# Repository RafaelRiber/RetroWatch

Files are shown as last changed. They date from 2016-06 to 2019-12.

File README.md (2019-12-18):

# RetroWatch
 <p align="center">
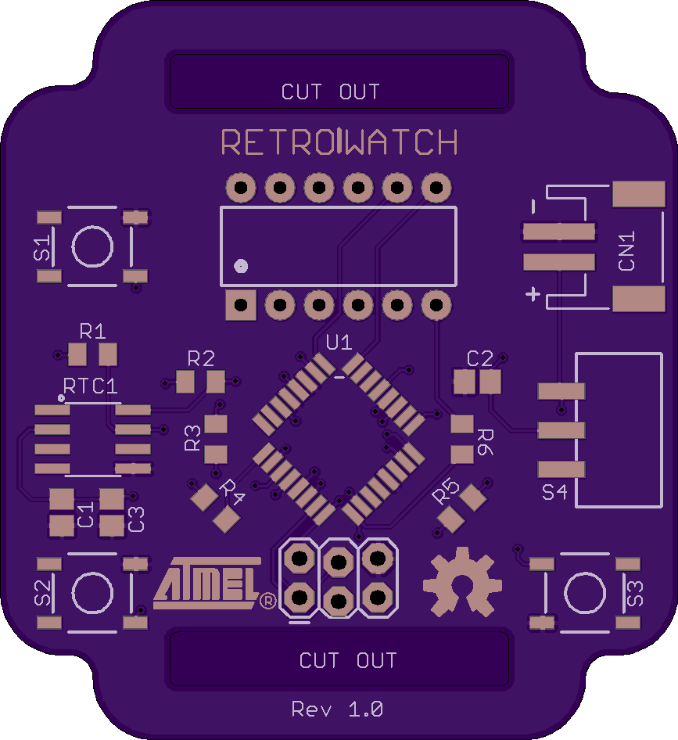
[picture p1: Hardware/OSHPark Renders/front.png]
 
 <em>Front</em>
 <p align="center">
 <b>OSHPark renders</b>
 </p>
 
## Short description
A retro watch, based around the HP QDSP-6064 Bubble display, used in 70s HP calculators like the [HP-35](https://en.wikipedia.org/wiki/HP-35). The display is controlled by an Atmel ATMega328P-AU MCU with Arduino code, and the time is kept by a Maxim DS3231 Real-Time Clock module, that stays connected to the LiPo battery at all times, keeping time even when the microcontroller and display are not powered.
The code is open source, licensed under the MIT License, and the harware is fully open-source.

### Featured on:
[Hackaday.com blog post by Elliot Williams](http://hackaday.com/2016/06/25/easy-bubble-watch-oozes-retro-charm/)

[Hackaday.io project page](https://hackaday.io/project/12402-retrowatch)
  
## Hardware
### PCB
The board design was made in Eagle, has been tested and works. A 500 mAh [LiPo Battery from Adafruit](https://adafru.it/1578) fits perfectly under the board. It can be freely modified. It can also directly be ordered on the OSHPark website: 
<p align="center"></p>

(DISCLAIMER: I am in no way affiliated with Atmel. I just put the Atmel logo on the PCB to show the circuit uses an Atmel chip, which I really like !)

### Bill Of Materials
You can find the BOM [here](https://github.com/RafaelRiber/RetroWatch/blob/master/BOM.md).
  
## Software
The software was written in Arduino code, is licensed under MIT License, and can be uploaded on the microcontroller via ISP.
Be sure to set the desired time in the code prior to uploading, to set the time registers on the RTC.

Functions of the code include:
* Hours, minutes and seconds
* Day, month, year, day of year, day in week, week in year.
* Stopwatch (start, stop, reset)
* Temperature reading from the real-time-clock's built-in thermometer (accurate to about 3°C)
* Brightness setting in software, saved to EEPROM to save even if the watch is powered off.
 
To be able to upload the code on the watch, an Arduno IDE board file for an "ATMega328 on a breadboard" running at 8 MHz with the internal crystal, is needed. You can find it here: https://www.arduino.cc/en/Tutorial/ArduinoToBreadboard under "Minimal Circuit (Eliminating the External Clock)"
### Required Libraries
1. [Chrono library by thomasfredericks](https://github.com/thomasfredericks/Chrono)
2. [Pushbutton library from Pololu](http://pololu.github.io/pushbutton-arduino/)
3. [RTCLib by Adafruit Industries](https://github.com/adafruit/RTClib)
4. [SevSeg by SparkFun](https://github.com/sparkfun/SevSeg)

### Planned Sofware Functions
• ~~Menu structure for mode selection~~ DONE !

• ~~Year~~ DONE !

• Time set on the watch

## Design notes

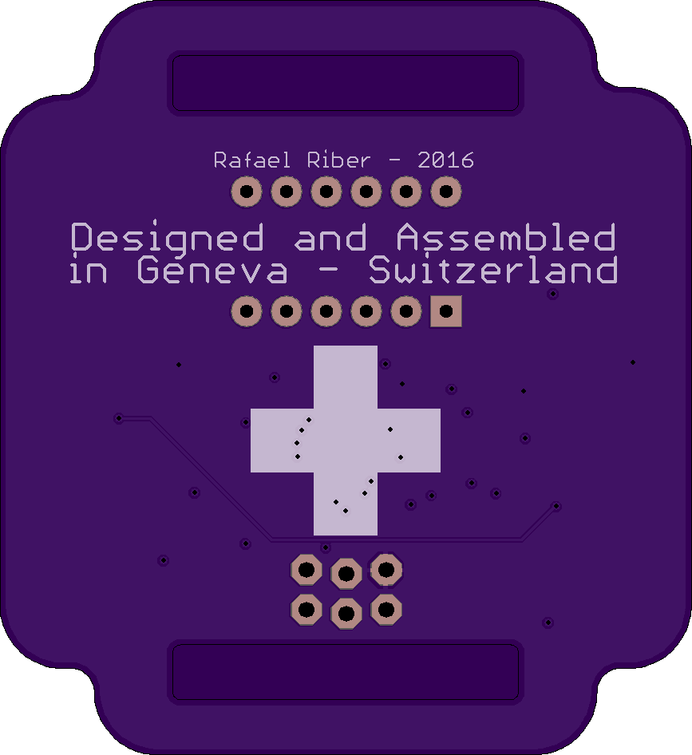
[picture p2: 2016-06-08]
Hardware/OSHPark Renders/back.png

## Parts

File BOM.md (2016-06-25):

###Bill of Materials:
<p>
<table>
<tr><td><b>Part</b></td><td><b>Value</b></td><td><b>Device</b></td><td><b>Package</b></td><td><b>Description</b></td><td><b></b></td></tr>
<tr><td>C1</td><td>0.1 uF</td><td>C-USC0805</td><td>C0805</td><td>CAPACITOR, American symbol</td><td></td></tr>
<tr><td>C2</td><td>0.1 uF</td><td>C-USC0805</td><td>C0805</td><td>CAPACITOR, American symbol</td><td></td></tr>
<tr><td>C3</td><td>1 uF</td><td>C-USC0805</td><td>C0805</td><td>CAPACITOR, American symbol</td><td></td></tr>
<tr><td>CN1</td><td>JST-PH</td><td>JST_2PIN-SMT-RA</td><td>JST-PH-2-SMT-RA</td><td>JST 2-Pin Connectors of various flavors</td><td></td></tr>
<tr><td>DISP1</td><td>HP QDSP 6064</td><td>7-SEGMENT-4DIGIT-COUNTER-HP-BUBBLE</td><td>DIL12</td><td></td><td></td></tr>
<tr><td>R1</td><td>10k</td><td>R-US_R0805</td><td>R0805</td><td>RESISTOR, American symbol</td><td></td></tr>
<tr><td>R2</td><td>10k</td><td>R-US_R0805</td><td>R0805</td><td>RESISTOR, American symbol</td><td></td></tr>
<tr><td>R3</td><td>220R</td><td>R-US_R0805</td><td>R0805</td><td>RESISTOR, American symbol</td><td></td></tr>
<tr><td>R4</td><td>220R</td><td>R-US_R0805</td><td>R0805</td><td>RESISTOR, American symbol</td><td></td></tr>
<tr><td>R5</td><td>220R</td><td>R-US_R0805</td><td>R0805</td><td>RESISTOR, American symbol</td><td></td></tr>
<tr><td>R6</td><td>220R</td><td>R-US_R0805</td><td>R0805</td><td>RESISTOR, American symbol</td><td></td></tr>
<tr><td>RTC1</td><td>DS3231M</td><td>DS3231M</td><td>SOIC8</td><td>DS3231M Real Time Clock.  Accuracy +/-5ppm.  Battery Backup.  2.3V to 5.5V.</td><td></td></tr>
<tr><td>S1</td><td>SKQGAFE010</td><td>SWITCH-MOMENTARY-2SMD</td><td>TACTILE-SWITCH-SMD</td><td>Various NO switches- pushbuttons, reed, etc</td><td></td></tr>
<tr><td>S2</td><td>SKQGAFE010</td><td>SWITCH-MOMENTARY-2SMD</td><td>TACTILE-SWITCH-SMD</td><td>Various NO switches- pushbuttons, reed, etc</td><td></td></tr>
<tr><td>S3</td><td>SKQGAFE010</td><td>SWITCH-MOMENTARY-2SMD</td><td>TACTILE-SWITCH-SMD</td><td>Various NO switches- pushbuttons, reed, etc</td><td></td></tr>
<tr><td>S4</td><td>SS SMD402</td><td>SWITCH-SPDTSMD2</td><td>SWITCH-SPDT-SMD</td><td>SPDT Switch</td><td></td></tr>
<tr><td>U1</td><td>ATMEGA328P-AU</td><td>ATMEGA328P-AU</td><td>TQFP32</td><td>8-bit Microcontroller with In-System Programmable Flash</td><td></td></tr>
</table>

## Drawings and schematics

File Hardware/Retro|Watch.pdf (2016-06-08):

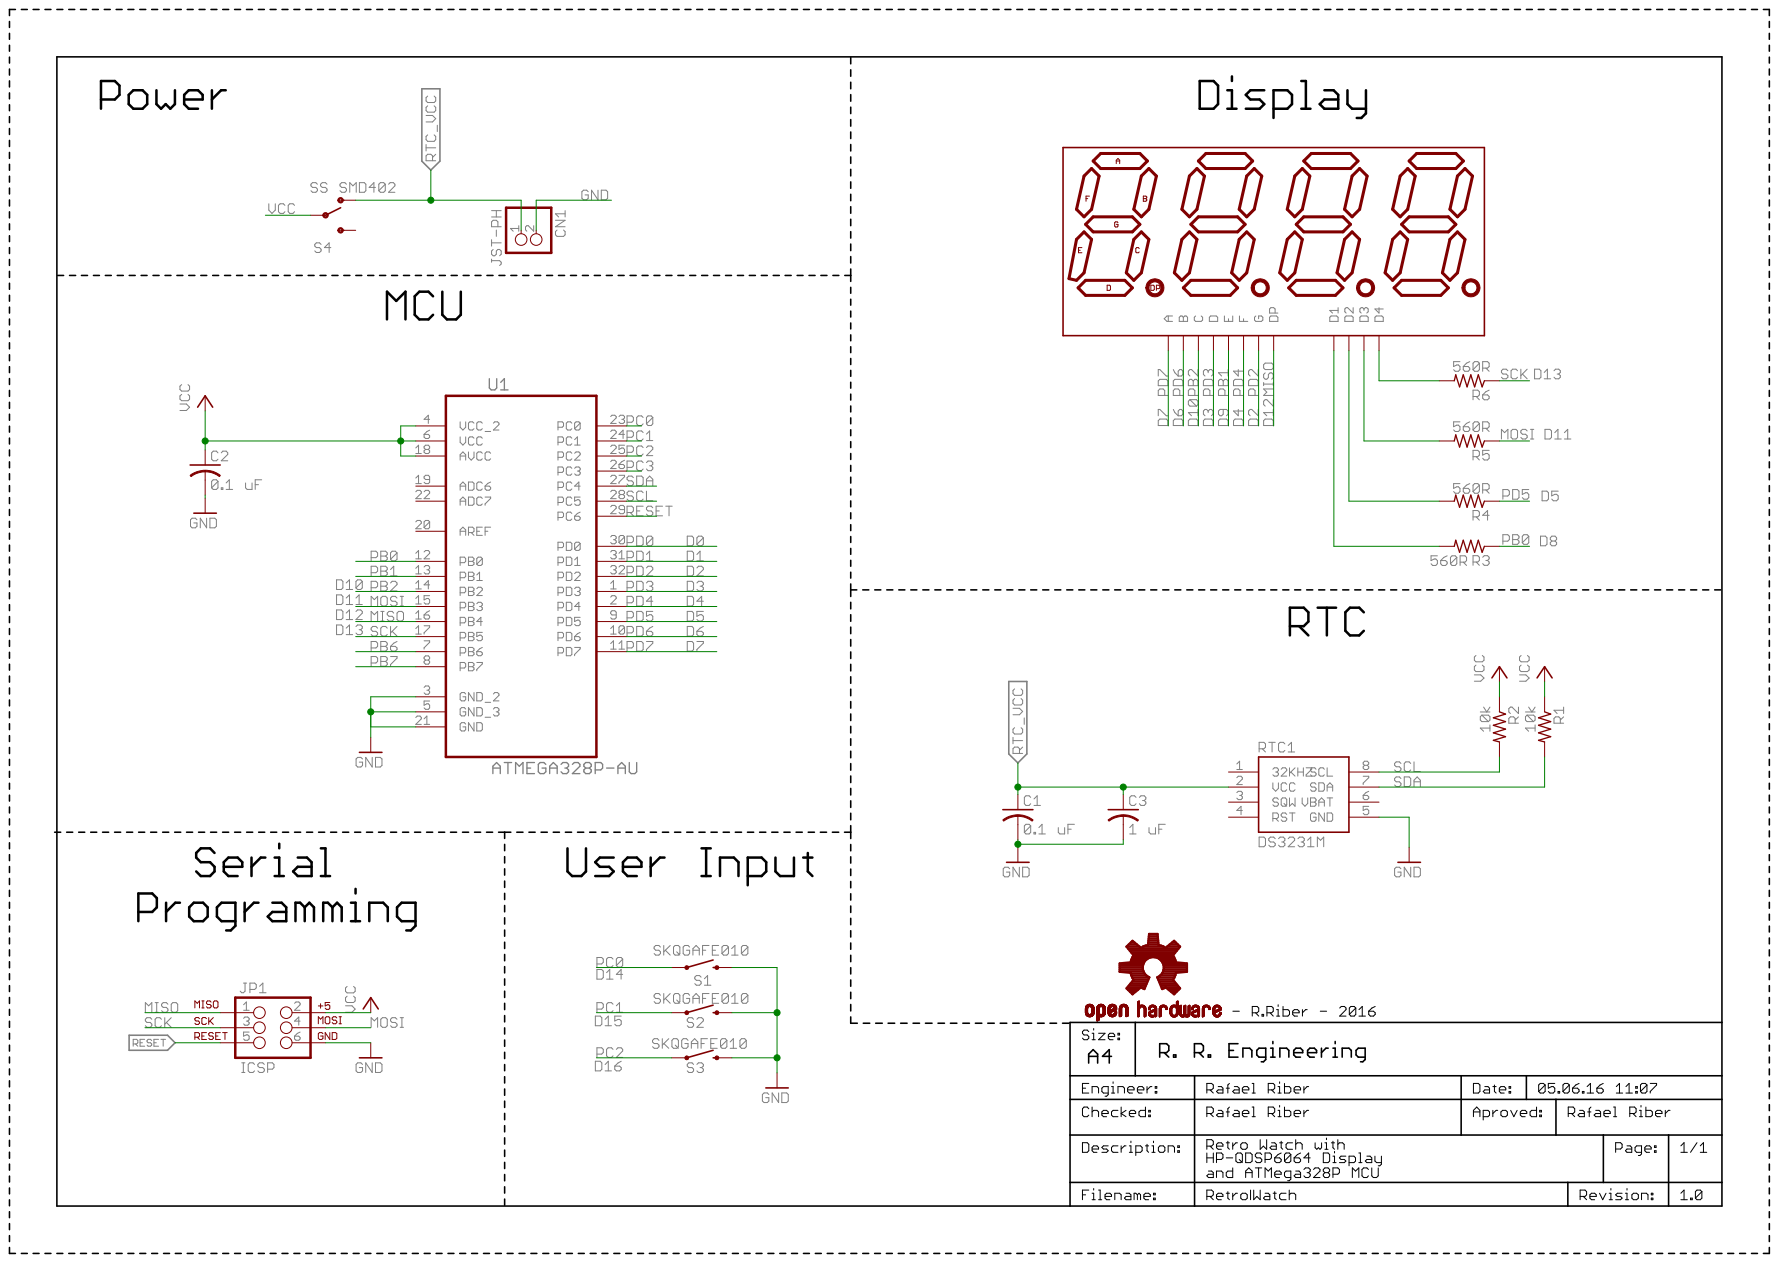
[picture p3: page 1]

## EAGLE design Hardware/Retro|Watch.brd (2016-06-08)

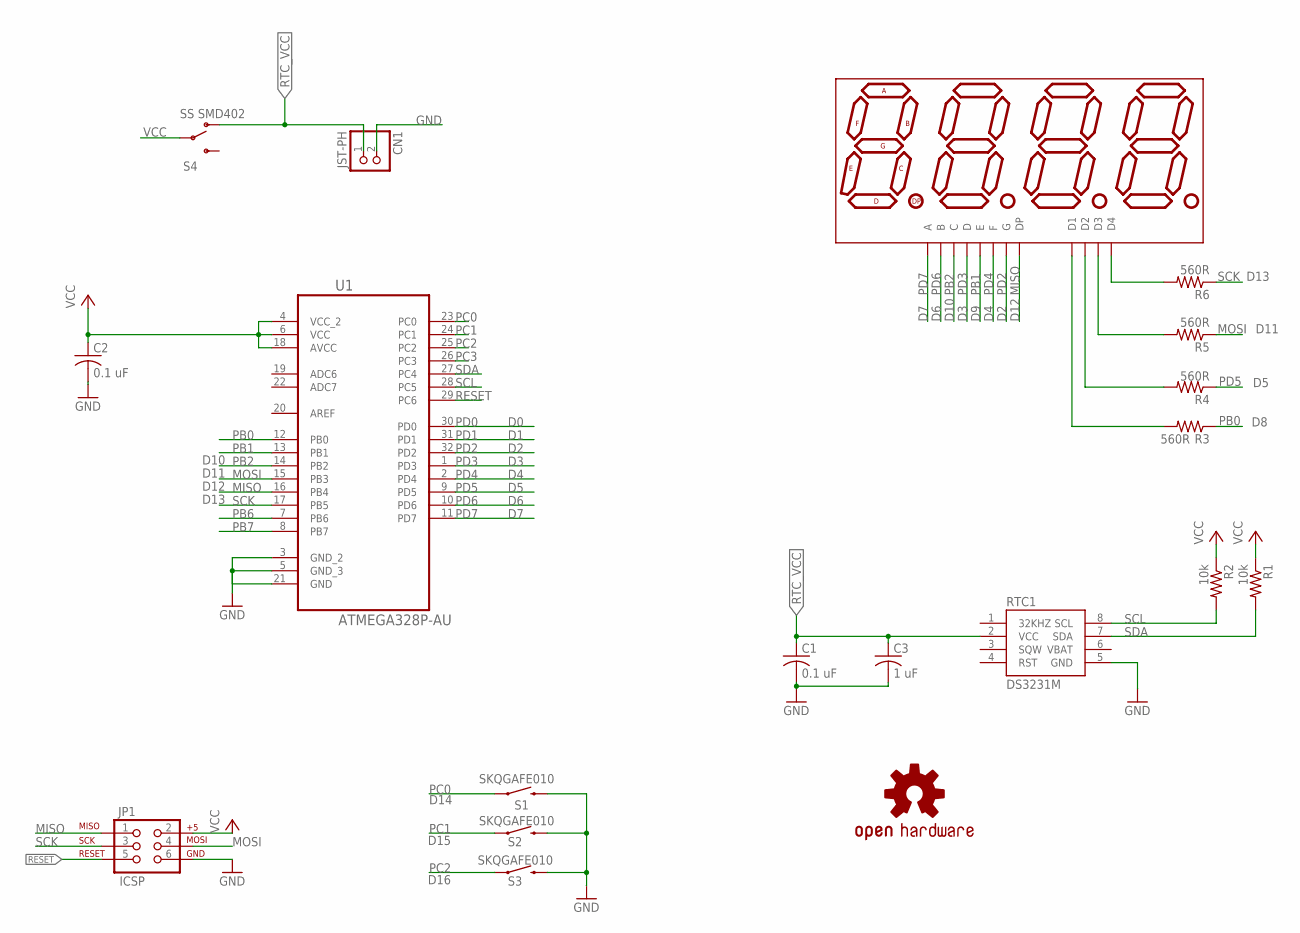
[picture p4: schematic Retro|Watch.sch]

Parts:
C1, C2: 0.1 uF; C0805; MPN 0805B104K500CT
C3: 1 uF; C0805
CN1: JST-PH; JST-PH-2-SMT-RA
DISP1: hp; DIL12
JP1: ICSP; 2X3_LOCK
LOGO1: OSHW-LOGOM-COPPER; OSHW-LOGO-M_COPPER
R1, R2: 10k; R0805
R3, R4, R5, R6: 560R; R0805
RTC1: DS3231M; SOIC8
S1, S2, S3: SKQGAFE010; TACTILE-SWITCH-SMD
S4: SS SMD402; SWITCH-SPDT-SMD
U1: ATMEGA328P-AU; QFP80P900X900X120-32N

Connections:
GND: C1.2, C2.2, C3.2, CN1.2 (1), JP1.6, RTC1.5 (GND), S1.3 (2), S2.3 (2), S3.3 (2), U1.3 (GND_2), U1.5 (GND_3), U1.21 (GND)
MISO: DISP1.5 (DP), JP1.1, U1.16 (PB4)
MOSI: JP1.4, R5.1, U1.15 (PB3)
unnamed: DISP1.1 (D1), R3.2
unnamed: DISP1.10 (D2), R4.2
unnamed: DISP1.4 (D3), R5.2
unnamed: DISP1.6 (D4), R6.2
PB0: R3.1, U1.12 (PB0)
PB1: DISP1.2 (E), U1.13 (PB1)
PB2: DISP1.3 (C), U1.14 (PB2)
PB6: U1.7 (PB6)
PB7: U1.8 (PB7)
PC0: S1.1, U1.23 (PC0)
PC1: S2.1, U1.24 (PC1)
PC2: S3.1, U1.25 (PC2)
PC3: U1.26 (PC3)
PD0: U1.30 (PD0)
PD1: U1.31 (PD1)
PD2: DISP1.7 (G), U1.32 (PD2)
PD3: DISP1.8 (D), U1.1 (PD3)
PD4: DISP1.9 (F), U1.2 (PD4)
PD5: R4.1, U1.9 (PD5)
PD6: DISP1.11 (B), U1.10 (PD6)
PD7: DISP1.12 (A), U1.11 (PD7)
RESET: JP1.5, U1.29 (PC6)
RTC_VCC: C1.1, C3.1, CN1.1 (2), RTC1.2 (VCC), S4.1 (O)
SCK: JP1.3, R6.1, U1.17 (PB5)
SCL: R2.2, RTC1.8 (SCL), U1.28 (PC5)
SDA: R1.2, RTC1.7 (SDA), U1.27 (PC4)
VBAT: RTC1.6 (VBAT)
VCC: C2.1, JP1.2, R1.1, R2.1, S4.2, U1.4 (VCC_2), U1.6 (VCC), U1.18 (AVCC)

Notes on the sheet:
D14
D15
D10
D11
D12
D13
D16

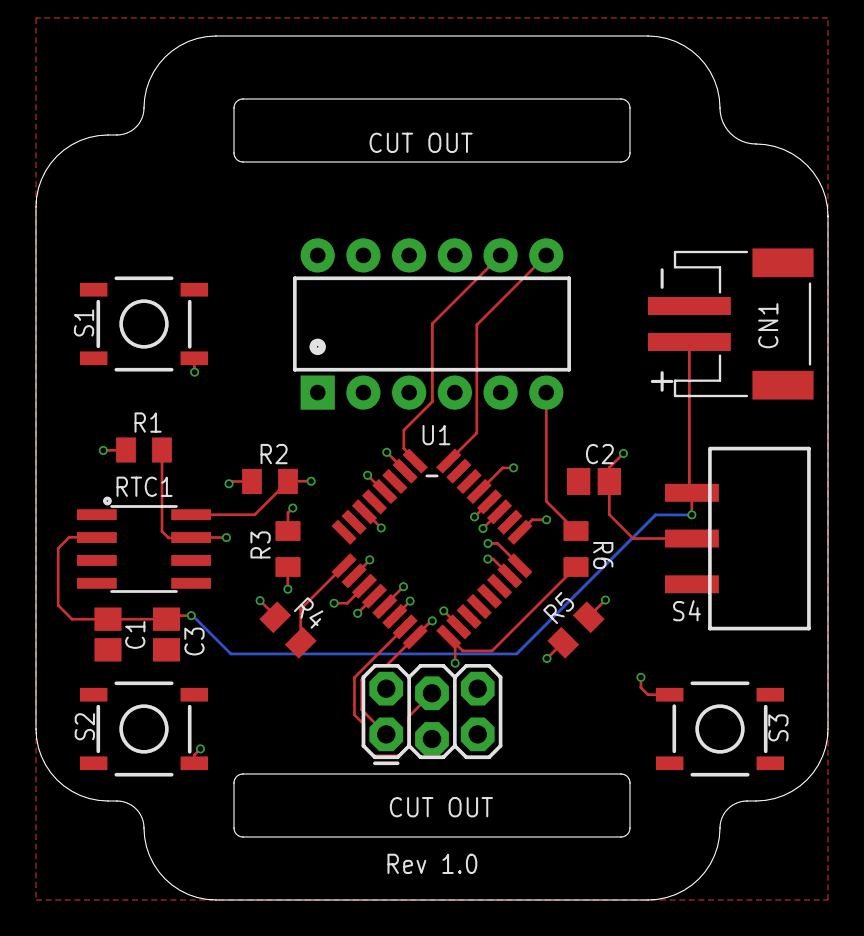
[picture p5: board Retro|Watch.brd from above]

Board: 4 copper layers, 44.0 x 48.0 mm, 20 parts (0 on the bottom side), 25 nets.

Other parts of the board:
U$1: LOGO

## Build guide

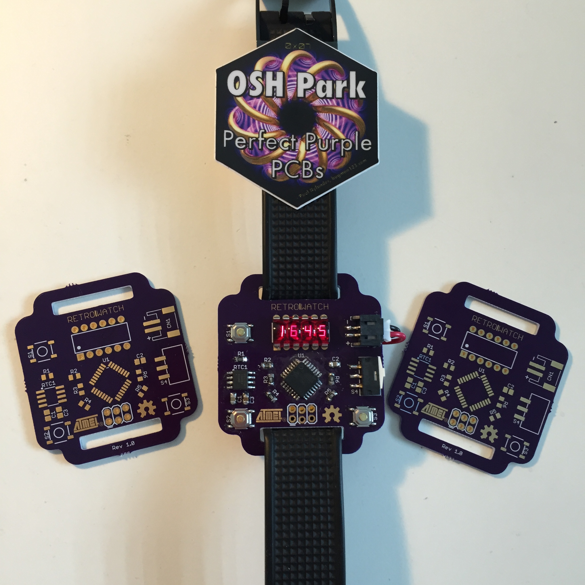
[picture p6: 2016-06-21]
Hardware/Assembled.JPG

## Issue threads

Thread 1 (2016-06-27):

DS3231M  power to VBAT

bobricius, 2016-06-27:
Hi, connect power for DS3231 to VBAT instead VCC (VCC>GND) it reduce standby power consumption from 200uA to 2uA, but if you have not using any standby modes in firmware it is useless. ;)

RafaelRiber, 2016-06-27:
Thanks for the tip ! I'll implement this in V2.

RafaelRiber, 2016-06-27:
Just a little question: should I power it only by VBAT, or use VCC when the Microcontroller is on, and VBAT when only the DS3231 is on ?

bobricius, 2016-06-27:
connect vcc to gnd and you can power DS3231 via vbat. I have using this in my watches, I have detection on startup with IIC scan if is DS3231 connected if not I start Timer2 in async mode .... there is complete MCU consumtion 0.9uA !!! so I decided to remove all charging related circuits. I read comments in sprakfun bigtime firmware that with this consumption you can display time every hour for 3years ... but of course I am not test it. Some tips about charging, load sharing, ds3231 ... http://blog.zakkemble.co.uk/diy-digital-wristwatch/ and about low power design you can read here https://github.com/sparkfun/BigTime/blob/master/Firmware/BigTime/BigTime.ino

RafaelRiber, 2016-06-27:
Ok I see. Thanks ! I'll do that in V2. I decided to stick with using a switch to cut power to the MCU instead of ultra-low power sleep, becuase I wanted to keep it as simple as possible. I will definetely look into it for future projects though ! Also, thanks for the links !

Closed 2016-06-27.

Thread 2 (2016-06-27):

Battery and watch strap not included in BOM.

phreaknik, 2016-06-27:
What battery and strap were used?

RafaelRiber, 2016-06-27:
I used a 500mAh Lithium Ion Polymer battery from Adafruit: **https://adafru.it/1578**
and an old strap from a random watch I had.
Any **20mm width** strap that's only in **one piece**, like **[this one](https://www.amazon.com/ArtStyle-Thickness-Quality-Brushed-Buckle/dp/B01AWP0U52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)** should do.

Closed 2016-06-27.

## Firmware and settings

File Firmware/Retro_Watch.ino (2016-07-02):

//The MIT License (MIT)
//
//Copyright (c) 2016 Rafael Riber
//
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
//Include required libraries
#include <Chrono.h>
#include <LightChrono.h>
#include <RTClib.h>
#include <Wire.h>
#include <SevSeg.h>
#include <Pushbutton.h>
#include <EEPROM.h>
#include <avr/wdt.h>

//Define constants
#define BUTTON1 14
#define BUTTON2 15
#define BUTTON3                     16
#define DS3231_I2C_ADDR             0x68
#define DS3231_TEMPERATURE_MSB      0x11
#define DS3231_TEMPERATURE_LSB      0x12

//Init objects
Pushbutton button1(BUTTON1);
Pushbutton button2(BUTTON2);
Pushbutton button3(BUTTON3);
SevSeg sevSeg;
RTC_DS3231 rtc;

Chrono myChrono(Chrono::SECONDS);

//Declare vars
byte temp_msb;
byte temp_lsb;
unsigned long timer;
unsigned int seconds;
unsigned int minutes;
unsigned int hours;
unsigned int months;
unsigned int days;
unsigned int year;
unsigned int doy;
unsigned int dow;
unsigned int woy;
unsigned int time_show;
unsigned long display_time;
unsigned long display_date;
unsigned long temp;
unsigned long deciSecond;
int count = 1;
int addr = 0;
int menu;
int mode;
int watch;
int brightness;
int date;

//Software reset function
void softwareReset(uint8_t prescaller) {
  wdt_enable(prescaller);
  while(1) {}
}

//Get seconds from RTC
unsigned int get_seconds()
{
  DateTime now = rtc.now();
  seconds = now.second();
  return seconds;
}

//Get minutes from RTC
unsigned int get_minutes()
{
  DateTime now = rtc.now();
  minutes = now.minute();
  return minutes;
}

//Get hours from RTC
unsigned int get_hours()
{
  DateTime now = rtc.now();
  hours = now.hour();
  return hours;
}

//Get days from RTC
unsigned int get_days()
{
  DateTime now = rtc.now();
  days = now.day();

  return days;
}

//Get months from RTC
unsigned int get_months()
{
  DateTime now = rtc.now();
  months = now.month();
  return months;
}

unsigned int get_year()
{
  DateTime now = rtc.now();
  year = now.year();
  return year;
}

unsigned int get_doy()
{
  DateTime now = rtc.now();
  doy = now.dayOfYear();
  return doy;
}

unsigned int get_dow()
{
  DateTime now = rtc.now();
  dow = now.dayOfTheWeek();
  return dow;
}

//Show hours and minutes on display
void show_hm()
{
  get_seconds();
  get_minutes();
  get_hours();

  display_time = (hours * 100) + minutes;

  char tempString[10];
  sprintf(tempString, "%04d", display_time);
  sevSeg.DisplayString(tempString, 2);
}

//Show minutes and seconds on display
void show_ms()
{
  get_seconds();
  get_minutes();
  get_hours();

  display_time = (minutes * 100) + seconds;

  char tempString[10];
  sprintf(tempString, "%04d", display_time);
  sevSeg.DisplayString(tempString, 2);
}

//Show date on display
//Show date on display
void show_date()
{
  char tempString[5];
  switch(date)
  {
    case 0:
      get_days();
      get_months();
      display_date = (days * 100) + months;
      sprintf(tempString, "%04d", display_date);
      sevSeg.DisplayString(tempString, 2);
      break;
    case 1:
      get_year();
      sprintf(tempString, "%4d", year);
      sevSeg.DisplayString(tempString, 0);
      break;
    case 2:
      get_doy();
      sprintf(tempString, "%4d", doy);
      sevSeg.DisplayString(tempString, 0);
      break;
    case 3:
      get_dow();
      sprintf(tempString, "%4d", dow);
      sevSeg.DisplayString(tempString, 0);
      break;
    case 4:
      get_doy();
      woy = doy / 7;
      sprintf(tempString, "%4d", woy);
      sevSeg.DisplayString(tempString, 0);
  }
  if (button2.getSingleDebouncedPress())
  {
    date = date - 1;
  }
  if (button3.getSingleDebouncedPress())
  {
    date++;
   }
   if (date < 0)
   {
    date = 4;
   }
   if (date > 4)
   {
    date = 0;
   }
}

//Get temperature from RTC
byte DS3231_get_MSB(){
 Wire.beginTransmission(DS3231_I2C_ADDR);
 Wire.write(DS3231_TEMPERATURE_MSB);
 Wire.endTransmission();

 Wire.requestFrom(DS3231_I2C_ADDR, 1);
 temp_msb = Wire.read();
}
byte DS3231_get_LSB(){

 Wire.beginTransmission(DS3231_I2C_ADDR);
 Wire.write(DS3231_TEMPERATURE_LSB);
 Wire.endTransmission();

 Wire.requestFrom(DS3231_I2C_ADDR, 1);
 temp_lsb = Wire.read() >> 6;
}

//Show temperature on display
void show_temp()
{
  char tempString[10];
  temp_msb = DS3231_get_MSB();
  temp_lsb = DS3231_get_LSB();
  
   switch(temp_lsb)
   {
     case 0:
       temp = (temp_msb*100);
       break;
     case 1 :
       temp = (temp_msb*100) + 25;
       break;
     case 2:
       temp = (temp_msb*100) + 50;
       break;
     case 3:
       temp = (temp_msb*100) + 75;
       break;
   }
  sprintf(tempString, "%04d", temp);
  sevSeg.DisplayString(tempString, 2);
}

void stopwatch()
{
  switch(count)
  {
    case 0:
      char tempString[10];
      if(myChrono.hasPassed(1))
      {
        deciSecond++;
        sprintf(tempString, "%04d", deciSecond);
        if(deciSecond < 10000)
        {
         sevSeg.DisplayString(tempString, 2);
        }
        if(deciSecond >= 10000)
        {
          sevSeg.DisplayString(tempString, 4);
        }
      }
      break;
    case 1:
      sprintf(tempString, "%04d", deciSecond);
      if(deciSecond < 10000)
      {
        sevSeg.DisplayString(tempString, 2);
      }
      if(deciSecond >= 10000)
      {
        sevSeg.DisplayString(tempString, 4);
      }
      break;
  }
  if (button3.getSingleDebouncedPress())
    {
      if (count <= 1)
      {
        count++;
      }
      if (count > 1)
      {
        count = 0;
      }
    }
    if (button2.getSingleDebouncedPress())
    {
      deciSecond = 0;
    }
}

void time()
{
  switch(time_show)
  {
    case 0:
      show_hm();
      break;
    case 1:
      show_ms();
      break;
  }
    if (button2.getSingleDebouncedPress())
  {
    time_show = time_show - 1;
  }
  if (button3.getSingleDebouncedPress())
  {
    time_show++;
   }
   if (time_show < 0)
   {
    time_show = 1;
   }
   if (time_show > 1)
   {
    time_show = 0;
   }
}

//Set brightness and save to EEPROM if different than before
void brightness_set()
{
  char tempString[5];
  sprintf(tempString, "%4d", brightness);
  sevSeg.DisplayString(tempString, 0);

  if (button2.getSingleDebouncedPress())
  {
    brightness = brightness - 1;
  }
  if (button3.getSingleDebouncedPress())
  {
    brightness = brightness + 1;
  }
  if (brightness > 10)
  {
    brightness = 10;
  }
  if (brightness < 0)
  {
    brightness = 0;
  }
  if (button1.getSingleDebouncedPress())
    {
      //Save brightness to EEPROM
      if(brightness != EEPROM.read(0))
      {
        EEPROM.write(0, brightness);
      }
      mode = 7;
      watch = 1;
    }
}

void menu_select()
{
  switch(menu)
  {
    case 0:
      sevSeg.DisplayString("Hour", 0);
      if (button1.getSingleDebouncedPress())
      {
        mode = 0;
        watch = 0;
      }
      break;
    case 1:
      sevSeg.DisplayString("Date", 0);
      if (button1.getSingleDebouncedPress())
      {
        mode = 1;
        watch = 0;
      }
      break;
    case 2:
      sevSeg.DisplayString("Chro", 0);
      if (button1.getSingleDebouncedPress())
      {
        mode = 2;
        watch = 0;
      }
      break;
    case 3:
      sevSeg.DisplayString("Heat", 0);
      if (button1.getSingleDebouncedPress())
      {
        mode = 3;
        watch = 0;
      }
      break;
    case 4:
      sevSeg.DisplayString("Brtx", 0);
      if (button1.getSingleDebouncedPress())
      {
        mode = 4;
        watch = 0;
      }
      break;
    case 5:
      sevSeg.DisplayString("Rstx", 0);
      if (button1.getSingleDebouncedPress())
      {
        mode = 5;
        watch = 0;
      }
      break;
  }
  
  if (button2.getSingleDebouncedPress())
  {
    menu = menu - 1;
  }
  if (button3.getSingleDebouncedPress())
  {
    menu++;
   }
   if (menu < 0)
   {
    menu = 0;
   }
   if (menu > 5)
   {
    menu = 5;
   }
}

void modes()
{
  switch(mode)
  {
    case 0:
      time();
      break;
    case 1:
      show_date();
      break;
    case 2:
      stopwatch();
      break;
    case 3:
      show_temp();
      break;
    case 4:
      brightness_set();
      break;
    case 5:
      softwareReset(WDTO_15MS);
      break;
   }
     if (mode < 0)
   {
    mode = 0;
   }
   if (mode > 5)
   {
    mode = 5;
   }
     if (button1.getSingleDebouncedPress())
     {
       watch++;
       if (watch > 1)
       {
         watch = 0;
       }
   }
}


//Initial setup
void setup()
{
  delay(10);
  rtc.begin();
  timer = millis();

  //Set time if RTC lost power
  if (rtc.lostPower())
  {
    // following line sets the RTC to the date & time this sketch was compiled
    //rtc.adjust(DateTime(F(__DATE__), F(__TIME__)));
    // This line sets the RTC with an explicit date & time:
    rtc.adjust(DateTime(2016, 6, 27, 19, 15, 0));
  }
  //Init display vars
  int displayType = COMMON_CATHODE;

  int digit1 = 8;
  int digit2 = 5;
  int digit3 = 11;
  int digit4 = 13;

  int segA = 7;
  int segB = 6;
  int segC = 10;
  int segD = 3;
  int segE = 9;
  int segF = 4;
  int segG = 2;
  int segDP = 12;

  int numberOfDigits = 4;

  sevSeg.Begin(displayType, numberOfDigits, digit1, digit2, digit3, digit4, segA, segB, segC, segD, segE, segF, segG, segDP);

  brightness = EEPROM.read(0);
}

//Main loop
void loop()
{ 
  sevSeg.SetBrightness(brightness * 10);
  switch(watch)
  {
    case 0:
      modes();
      break;
    case 1:
      menu_select();
      break;
  }
}

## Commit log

2016-06-08 Corrected temperature reading
2016-06-23 Moved in version folder
    [Retro|Watch.brd, Retro|Watch.sch]
2016-06-26 Added menu structure, stopwatch reset, and a base for on-watch time set
    Added menu structure, stopwatch reset, and a base for on-watch time
    set. The last function of the menu, « Set », returns a blank screen but
    is a base for on-watch time set.
    [Retro_Watch.ino]
2016-06-30 Changed directory structure
    [Retro|Watch.brd, Retro|Watch.sch]
2016-07-02 Updated RetroWatch.ino
    • Added day of year, day of week and week of year to date function.
    • Added brightness setting with save to EEPROM for power cycle save.
    • Added software reset function.
    • Improved menu navigation.
    • Joined hours, minutes and seconds in same function.
    • General code cleanup
    [Retro_Watch.ino]

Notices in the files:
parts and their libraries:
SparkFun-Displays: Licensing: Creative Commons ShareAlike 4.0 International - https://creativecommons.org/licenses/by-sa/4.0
